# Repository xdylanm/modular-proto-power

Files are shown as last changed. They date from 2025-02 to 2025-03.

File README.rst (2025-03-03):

Prototype Power
===============

A module in the Eurorack format that provides power pins and basic signals for prototyping.

Features
--------

Power Headers
^^^^^^^^^^^^^

Power headers are broken out at the front panel

* 16P IDC connector with Eurorack "standard" pinout for power distribution 

    * Reference: https://division-6.com/learn/eurorack-power/
    * Use keyed IDC connectors and housings and associate -12V with pin 1. Ensure cables are oriented correctly (red stripe to pin 1).

* 1x3 headers for +12V, +5V, ground, and -12V

*Note*: Doepfer, who started the mess of using ribbon cables and IDC connectors for power distribution, explicitly avoids keyed housings for the connectors in favour of open 2x8 pin headers (https://doepfer.de/a100_man/a100t_e.htm). In this case, you are expected to rely on board markings or, worse, location of the header on the PCB, to determine the orientation. This is dumb. It's straightforward to confirm that the cable orientation matches the keying on the connectors (check both ends and any mid-cable connectors), which ultimately makes assembly and connection simpler.

Buffers/DC Outputs
^^^^^^^^^^^^^^^^^^

Two buffers are provided. The input of the second is normaled to the input of the first, enabling signal duplication.

* The first buffer is connected internally to a DC input with an adjustable :math:`\pm 10V` range. That connection is broken when the external input for buffer 1 is used.
* The input for the second buffer is connected internally (normaled) to the input for the first. That connection is broken when the external input for buffer 2 is used.

Gate and Envelope Generator
^^^^^^^^^^^^^^^^^^^^^^^^^^^

A 5V gate signal can be generated in one-shot (push button) or oscillator mode. Both the pulse length and frequency can be adjusted. The gate signal is also fed into a simple AR envelope with controls for attack and release, and the envelope is output.

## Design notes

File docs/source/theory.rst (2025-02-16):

Theory of Operation
===================

The 555 timer can be configured in both monostable (one-shot) and as an oscillator. 

Online calculator: https://www.build-electronic-circuits.com/circuit-calculator-conversion/555-timer-calculator/

Oscillator (Astable)
--------------------

In the astable configuration, 

.. math::

    T_{hi} &= 0.693(R_1 + R_2)C_1 \\ 
    T_{lo} &= 0.693 R_2 C_1 \\
    d_{hi} &= \frac{T_{hi}}{T_{hi} + T_{lo}} = \frac{R_1 + R_2}{R_1 + 2R_2}\\  
    f &= \frac{1.44}{(R_1 + 2R_2)C_1}

In the schematic below, :math:`R_1 \equiv R1 + RV1`, which ranges from 1k to 101k. :math:`R_2=22k\Omega` and :math:`C_1=10\mu F`.

====== ====== ========
R1 (k) f (Hz) duty (%)
====== ====== ========
1      3.2 Hz 52 %      
50     1.5    77
100    1.0    85 
====== ====== ========

The frequency scales inversely with :math:`C_1`: doubling :math:`C_1` will half the frequency.

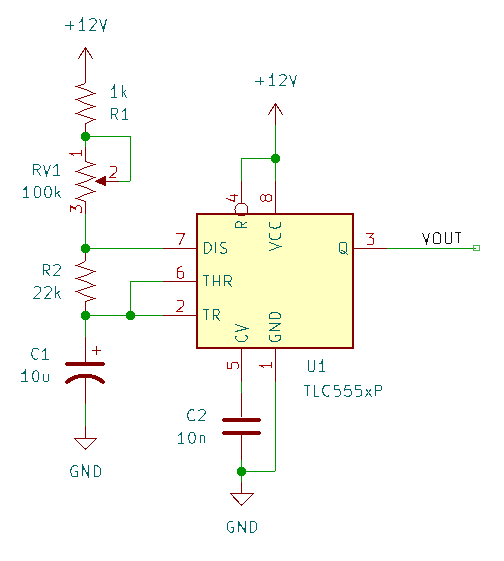
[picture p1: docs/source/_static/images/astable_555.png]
555 timer astable configuration


One-Shot (Monostable)
---------------------

In the monostable/one-shot configuration, a pulse that pulls TRIGGER low resets the timer by discharging :math:`C_1` via the DISCHARGE pin. This sets the output HI until :math:`C_1` charges again through :math:`R_1` and its voltage rises above the timer's threshold. 

.. math::

    T_{pulse} = 1.1 R_1 C_1

In the schematic below, :math:`R_1 \equiv R1 + RV1`, which ranges from 1k to 101k, and :math:`C_1=10\mu F`. The pulse time can be adjusted from 11ms to 1.1s.

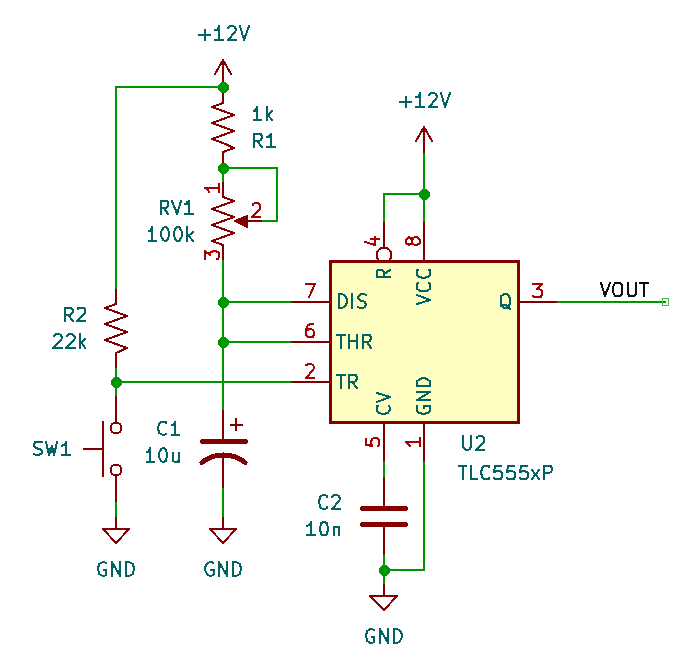
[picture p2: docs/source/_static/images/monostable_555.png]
555 timer monostable configuration


Selecting the Operating Mode
----------------------------

Comparing the two schematics above, we can see that switching between the two configurations involves

* connecting THR to TR (astable) or DIS (monostable)
* connecting :math:`R_2` to DIS (astable) or to +V

In the later case, the pull-down switch is still connected to TR, and can act as a sync. A DPDT toggle switch is used.

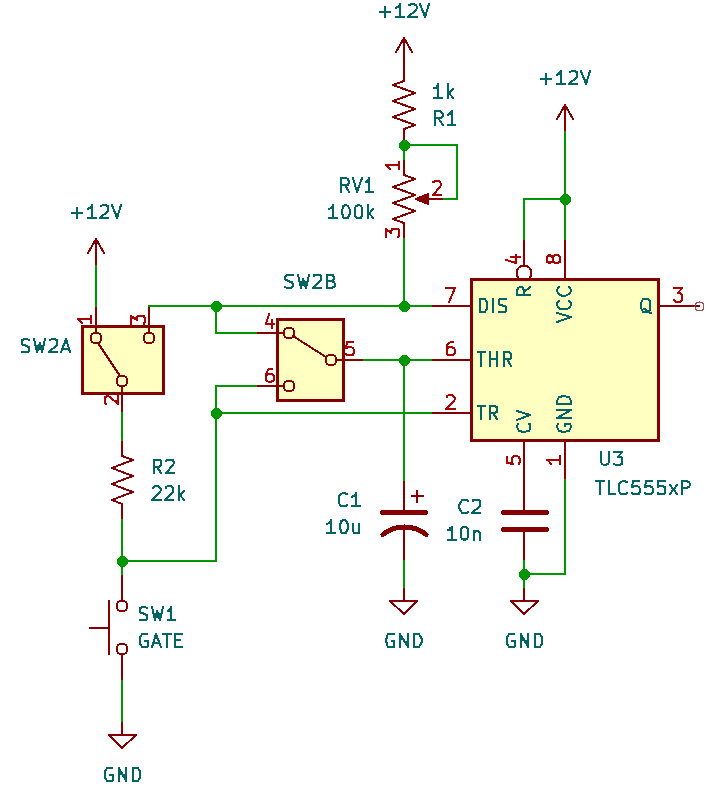
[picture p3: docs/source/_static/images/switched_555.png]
555 timer switching between configurations


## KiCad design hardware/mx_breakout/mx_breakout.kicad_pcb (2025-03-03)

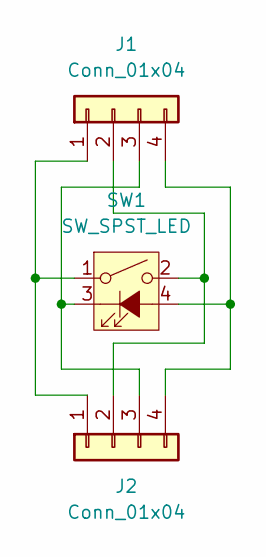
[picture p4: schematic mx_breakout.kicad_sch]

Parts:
J1, J2: Conn_01x04; PinHeader_1x04_P2.54mm_Vertical
SW1: SW_SPST_LED; SW_Cherry_MX_1.00u_LED_PCB

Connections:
unnamed: J1.1, J2.1, SW1.1
unnamed: J1.2, J2.2, SW1.2
unnamed: J1.3, J2.3, SW1.3 (K)
unnamed: J1.4, J2.4, SW1.4 (A)

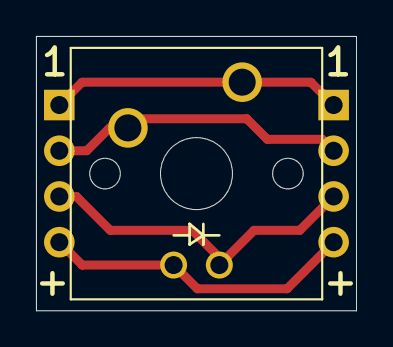
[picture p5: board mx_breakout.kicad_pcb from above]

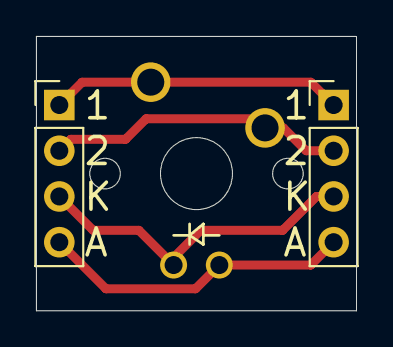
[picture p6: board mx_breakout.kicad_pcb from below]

Board: 2 copper layers, 17.8 x 15.2 mm, 3 parts (2 on the bottom side), 4 nets.

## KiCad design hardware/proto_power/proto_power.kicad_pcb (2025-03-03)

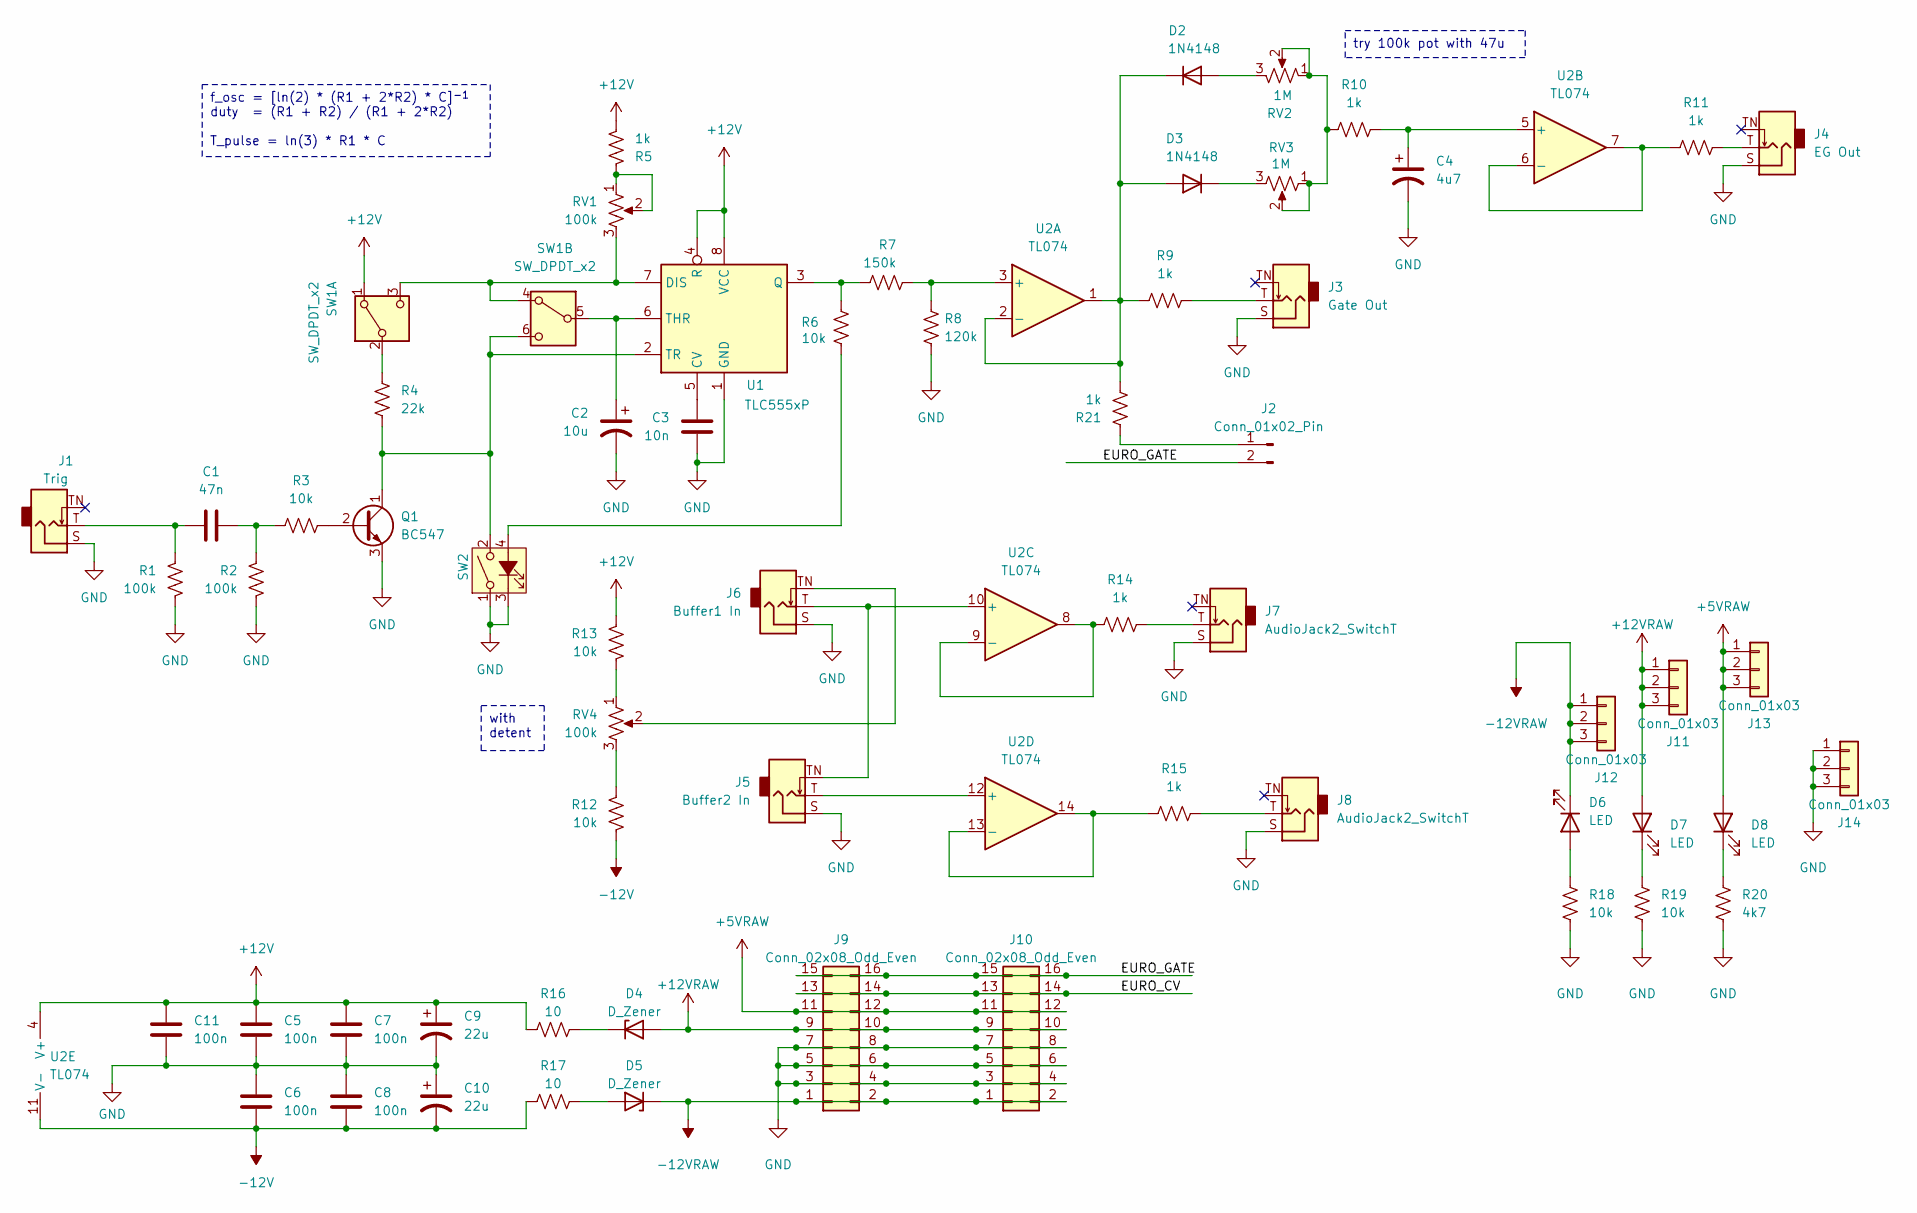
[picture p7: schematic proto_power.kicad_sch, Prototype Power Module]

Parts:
C1: 47n; C_Disc_D4.7mm_W2.5mm_P5.00mm
C2: 10u; CP_Radial_D4.0mm_P2.00mm
C3: 10n; C_Disc_D4.7mm_W2.5mm_P5.00mm
C4: 4u7; CP_Radial_D4.0mm_P2.00mm
C5, C6, C7, C8, C11: 100n; C_Disc_D4.7mm_W2.5mm_P5.00mm
C9, C10: 22u; CP_Radial_D5.0mm_P2.50mm
D2, D3: 1N4148; D_DO-35_SOD27_P7.62mm_Horizontal
D4, D5: D_Zener; D_DO-41_SOD81_P7.62mm_Horizontal
D6, D7, D8: LED; LED_D3.0mm
J1: Trig; Jack_3.5mm_QingPu_WQP-PJ301M-12_Vertical
J2: Conn_01x02_Pin; PinHeader_1x02_P2.54mm_Vertical
J3: Gate Out; Jack_3.5mm_QingPu_WQP-PJ301M-12_Vertical
J4: EG Out; Jack_3.5mm_QingPu_WQP-PJ301M-12_Vertical
J5: Buffer2 In; Jack_3.5mm_QingPu_WQP-PJ301M-12_Vertical
J6: Buffer1 In; Jack_3.5mm_QingPu_WQP-PJ301M-12_Vertical
J7, J8: AudioJack2_SwitchT; Jack_3.5mm_QingPu_WQP-PJ301M-12_Vertical
J9, J10: Conn_02x08_Odd_Even; IDC-Header_2x08_P2.54mm_Vertical
J11, J12, J13, J14: Conn_01x03; PinSocket_1x03_P2.54mm_Vertical
Q1: BC547; TO-92_Inline_Wide
R1, R2: 100k; R_Axial_DIN0204_L3.6mm_D1.6mm_P2.54mm_Vertical
R3, R6, R18, R19: 10k; R_Axial_DIN0204_L3.6mm_D1.6mm_P2.54mm_Vertical
R4: 22k; R_Axial_DIN0204_L3.6mm_D1.6mm_P2.54mm_Vertical
R5, R9, R10, R15: 1k; R_Axial_DIN0204_L3.6mm_D1.6mm_P2.54mm_Vertical
R7: 150k; R_Axial_DIN0204_L3.6mm_D1.6mm_P2.54mm_Vertical
R8: 120k; R_Axial_DIN0204_L3.6mm_D1.6mm_P2.54mm_Vertical
R11, R14, R21: 1k; R_Axial_DIN0204_L3.6mm_D1.6mm_P7.62mm_Horizontal
R12, R13: 10k; R_Axial_DIN0204_L3.6mm_D1.6mm_P7.62mm_Horizontal
R16, R17: 10; R_Axial_DIN0204_L3.6mm_D1.6mm_P2.54mm_Vertical
R20: 4k7; R_Axial_DIN0204_L3.6mm_D1.6mm_P2.54mm_Vertical
RV1, RV4: 100k; Potentiometer_Bourns_PTV09A-1_Single_Vertical
RV2, RV3: 1M; Potentiometer_Bourns_PTV09A-1_Single_Vertical
SW1: SW_DPDT_x2; SW_DPDT_13mm_x_13mm_P5.00mm
SW2: SW_SPST_LED; SW_Cherry_MX_1.00u_Breakout
U1: TLC555xP; DIP-8_W7.62mm_Socket
U2: TL074; DIP-14_W7.62mm_Socket

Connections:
+5VRAW: D8.2 (A), J9.11, J9.12, J10.11, J10.12, J13.1, J13.2, J13.3
+12V: C5.1, C7.1, C9.1, C11.1, R5.2, R13.2, R16.1, SW1.1 (A), U1.4 (R), U1.8 (VCC), U2.4 (V+)
+12VRAW: D4.2 (A), D7.2 (A), J9.9, J9.10, J10.9, J10.10, J11.1, J11.2, J11.3
-12V: C6.2, C8.2, C10.2, R12.1, R17.1, U2.11 (V-)
-12VRAW: D5.1 (K), D6.1 (K), J9.1, J9.2, J10.1, J10.2, J12.1, J12.2, J12.3
/EURO_CV: J9.13, J9.14, J10.13, J10.14
/EURO_GATE: J2.2, J9.15, J9.16, J10.15, J10.16
GND: C2.2, C3.2, C4.2, C5.2, C6.1, C7.2, C8.1, C9.2, C10.1, C11.2, J1.S, J3.S, J4.S, J5.S, J6.S, J7.S, J8.S, J9.3, J9.4, J9.5, J9.6, J9.7, J9.8, J10.3, J10.4, J10.5, J10.6, J10.7, J10.8, J14.1, J14.2, J14.3, Q1.3 (E), R1.2, R2.2, R8.2, R18.2, R19.2, R20.2, SW2.1, SW2.3 (K), U1.1 (GND)
unnamed: C1.1, J1.T, R1.1
unnamed: C1.2, R2.1, R3.2
unnamed: D2.2 (A), RV2.3
unnamed: D2.1 (K), D3.2 (A), R9.1, R21.1, U2.1, U2.2 (-)
unnamed: D3.1 (K), RV3.3
unnamed: D4.1 (K), R16.2
unnamed: D5.2 (A), R17.2
unnamed: D6.2 (A), R18.1
unnamed: D7.1 (K), R19.1
unnamed: D8.1 (K), R20.1
unnamed: J2.1, R21.2
unnamed: J3.T, R9.2
unnamed: J4.T, R11.2
unnamed: J6.TN, RV4.2
unnamed: J7.T, R14.2
unnamed: J8.T, R15.2
unnamed: Q1.2 (B), R3.1
unnamed: Q1.1 (C), R4.2, SW1.6 (C), SW2.2, U1.2 (TR)
unnamed: R5.1, RV1.1, RV1.2
unnamed: R10.1, RV2.1, RV2.2, RV3.1, RV3.2
unnamed: R12.2, RV4.3
unnamed: R13.1, RV4.1
unnamed: R4.1, SW1.2 (B)
unnamed: RV1.3, SW1.3 (C), SW1.4 (A), U1.7 (DIS)
unnamed: C2.1, SW1.5 (B), U1.6 (THR)
unnamed: R6.1, SW2.4 (A)
unnamed: C3.1, U1.5 (CV)
unnamed: R6.2, R7.1, U1.3 (Q)
unnamed: R7.2, R8.1, U2.3 (+)
unnamed: C4.1, R10.2, U2.5 (+)
unnamed: R11.1, U2.6 (-), U2.7
unnamed: J5.TN, J6.T, U2.10 (+)
unnamed: R14.1, U2.8, U2.9 (-)
unnamed: J5.T, U2.12 (+)
unnamed: R15.1, U2.13 (-), U2.14

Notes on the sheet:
try 100k pot with 47u
with detent
f_osc = [ln(2) * (R1 + 2*R2) * C]^{-1} duty = (R1 + R2) / (R1 + 2*R2) T_pulse = ln(3) * R1 * C

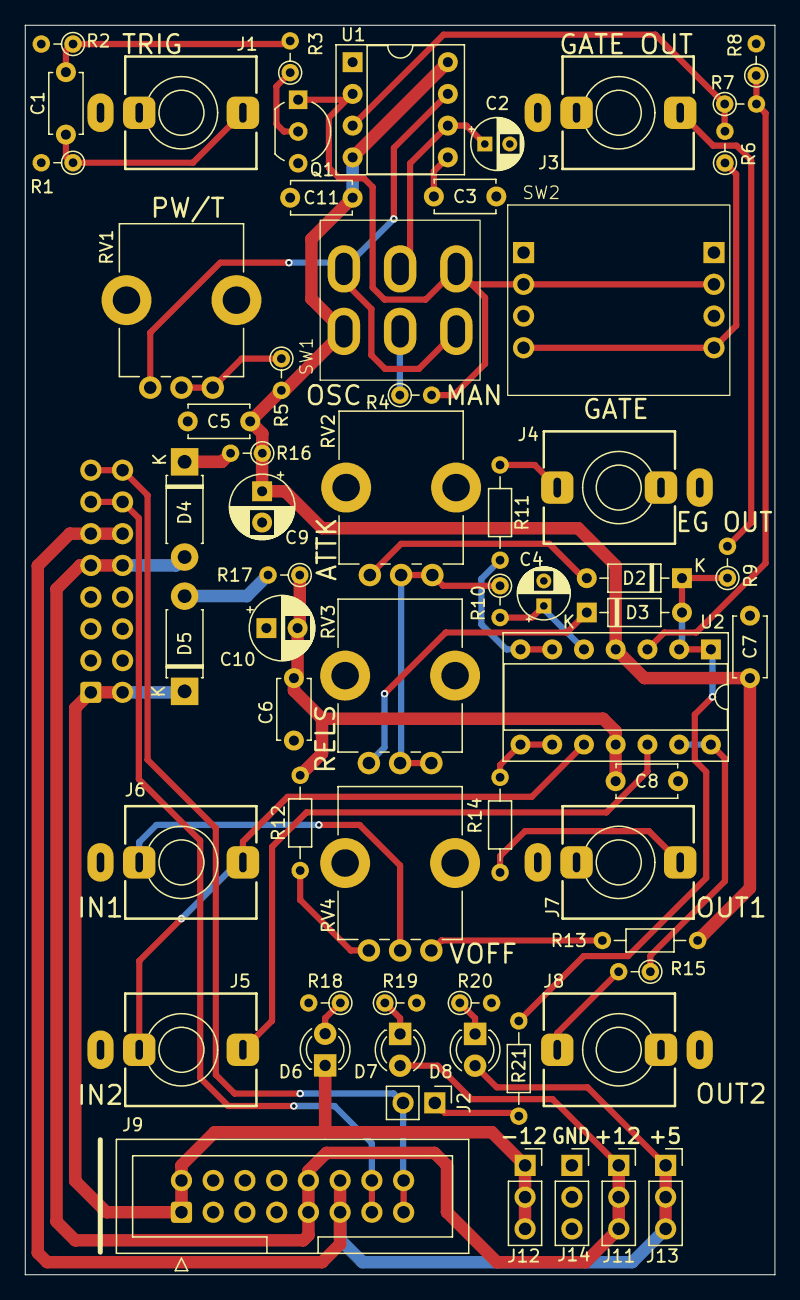
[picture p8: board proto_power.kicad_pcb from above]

Board: 2 copper layers, 60.0 x 100.0 mm, 62 parts (1 on the bottom side), 43 nets.

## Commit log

2025-02-16 Initial design for a prototyping power module. See README for details
    [proto_power.kicad_pcb, proto_power.kicad_sch]
2025-03-03 v1 board released for mfg.
    [mx_breakout.kicad_pcb, mx_breakout.kicad_sch, proto_power.kicad_pcb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]

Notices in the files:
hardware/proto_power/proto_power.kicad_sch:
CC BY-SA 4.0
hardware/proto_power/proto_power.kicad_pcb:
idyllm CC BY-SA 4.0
